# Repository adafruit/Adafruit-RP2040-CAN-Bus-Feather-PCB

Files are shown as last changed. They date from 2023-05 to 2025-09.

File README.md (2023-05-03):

## Adafruit RP2040 CAN Bus Feather with MCP2515 CAN Controller - STEMMA QT PCB

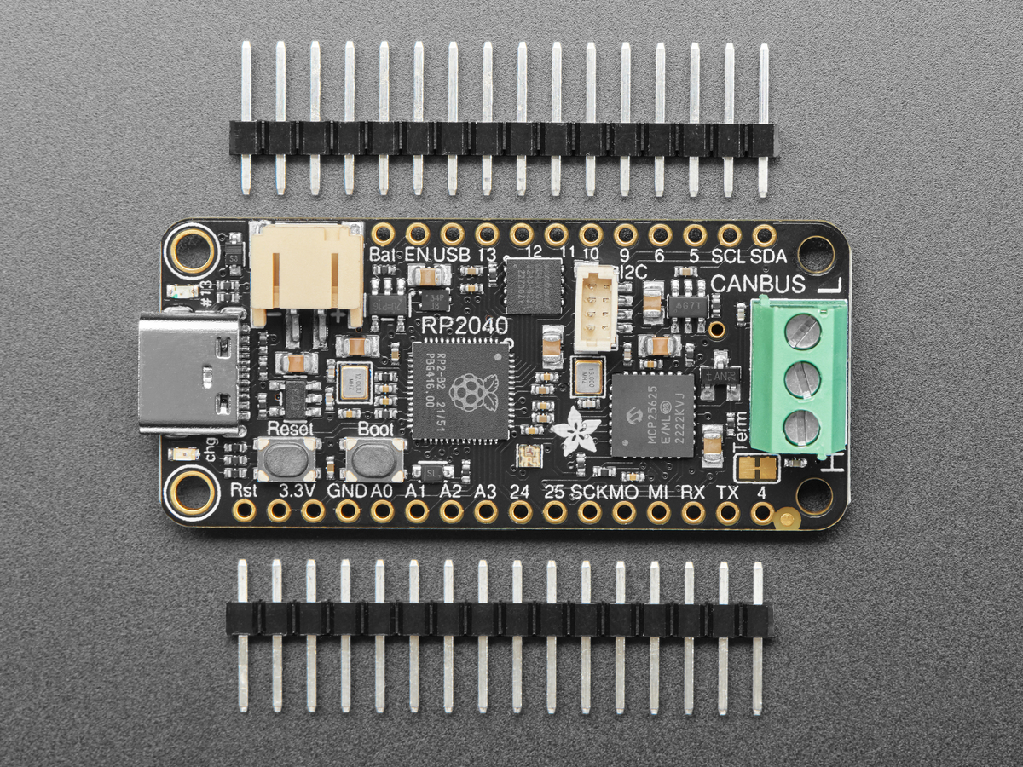
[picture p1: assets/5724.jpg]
<a href="http://www.adafruit.com/products/5724"><br/>
Click here to purchase one from the Adafruit shop</a>

PCB files for the Adafruit RP2040 CAN Bus Feather with MCP2515 CAN Controller - STEMMA QT. 

Format is EagleCAD schematic and board layout
* https://www.adafruit.com/product/5724

### Description

If you'd like to quickly get started with CAN bus interfacing, with no soldering required, our Adafruit RP2040 CAN Bus Feather comes ready-to-rock with a microcontroller, CAN chipset and terminal blocks for instant gratification. The controller used is the MCP26525 (aka a MCP2515 with built-in transciever), an extremely popular and well-supported chipset that has drivers in Arduino and CircuitPython and only requires an SPI port and two pins for chip-select and IRQ. Use it to send and receive messages in either standard or extended format at up to 1 Mbps.

Feather is the development board specification from Adafruit, and like its namesake, it is thin, light, and lets you fly! We designed Feather to be a new standard for portable microcontroller cores. We have other boards in the Feather family, check'em out here.

CAN Bus is a small-scale networking standard, originally designed for cars and, yes, busses, but is now used for many robotics or sensor networks that need better range and addressing than I2C and don't have the pins or computational ability to talk on Ethernet. CAN is 2 wire differential, which means it's good for long distances and noisy environments.

Messages are sent at about 1Mbps rate - you set the frequency for the bus and then all 'joiners' must match it, and have an address before the packet so that each node can listen in to messages just for it. New nodes can be attached easily because they just need to connect to the two data lines anywhere in the shared net. Each CAN device sends messages whenever it wants, and thanks to some clever data encoding, can detect if there's a message collision and retransmit later. 

We've added a few nice extras to this Feather to make it useful in many common CAN scenarios:

* 5V charge-pump voltage generator, so even though you are running 3.3V on a Feather board, it will generate a nice clean 5V as required by the interal transceiver.
* 3.5mm soldered terminal block quick access to the High and Low data lines as well as a ground pin, without any soldering.
* 120-ohm termination resistor on board, you can remove the termination easily by cutting the jumper marked TERM on the top of the board.
* CAN control CS, Reset, Int, standby pins connected internally so you can use any FeatherWing without pin conflicts.

At the Feather's heart is an RP2040 chip, clocked at 133 MHz and at 3.3V logic, the same one used in the Raspberry Pi Pico. This chip has a whopping 8 MB of onboard QSPI FLASH and 264K of RAM!  There's even room left over for a STEMMA QT connector for plug-and-play of I2C devices.

To make it easy to use for portable projects, we added a connector for any of our 3.7V Lithium polymer batteries and built-in battery charging. You don't need a battery, it will run just fine straight from the USB Type C connector. But, if you do have a battery, you can take it on the go, then plug in the USB to recharge. The Feather will automatically switch over to USB power when it's available.

Here're some handy specs! You get:

* Measures 2.0" x 0.9" x 0.28" (50.8mm x 22.8mm x 7mm) without headers soldered in
* Light as a (large?) feather - 6.3 grams
* RP2040 32-bit Cortex M0+ dual core running at ~133 MHz @ 3.3V logic and power
* 264 KB RAM
* 8 MB SPI FLASH chip for storing files, images and CircuitPython/MicroPython code storage. No EEPROM
* Tons of GPIO! 21 x GPIO pins with following capabilities:
	* Four 12-bit ADCs (one more than Pico)
	* Two I2C, Two SPI, and two UART peripherals, we label one for the 'main' interface in standard Feather locations
	* 16 x PWM outputs - for servos, LEDs, etc
* Built-in 200mA+ lipoly charger with charging status indicator LED
* Pin #13 red LED for general purpose blinking
* RGB NeoPixel for full-color indication.
* On-board STEMMA QT connector that lets you quickly connect any Qwiic, STEMMA QT or Grove I2C devices with no soldering!
* Both Reset button and Bootloader select button for quick restarts (no unplugging-replugging to relaunch code)
* USB Type C connector lets you access built-in ROM USB bootloader and serial port debugging
* 3.3V regulator with 500mA peak current output and power enable pin
* 4 mounting holes
* 12 MHz crystal for perfect timing.
* Support circuitry for CAN Bus using SPI interface

Comes assembled and tested, with some header. You'll need a soldering iron to attach the header for installing onto your Feather. Stacking headers will let you put another FeatherWing on top.

### License

Adafruit invests time and resources providing this open source design, please support Adafruit and open-source hardware by purchasing products from [Adafruit](https://www.adafruit.com)!

Designed by Limor Fried/Ladyada for Adafruit Industries.

Creative Commons Attribution/Share-Alike, all text above must be included in any redistribution. 
See license.txt for additional details.

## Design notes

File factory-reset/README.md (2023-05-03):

## Factory Reset file - RP2040 CAN Bus Feather with MCP2515 CAN Controller - STEMMA QT

This is the factory reset file for the RP2040 CAN Bus Feather with MCP2515 CAN Controller - STEMMA QT.

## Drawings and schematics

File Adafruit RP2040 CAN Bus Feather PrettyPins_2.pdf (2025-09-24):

# Adafruit RP2040 CAN Bus Feather

# https://www.adafruit.com/product/5724

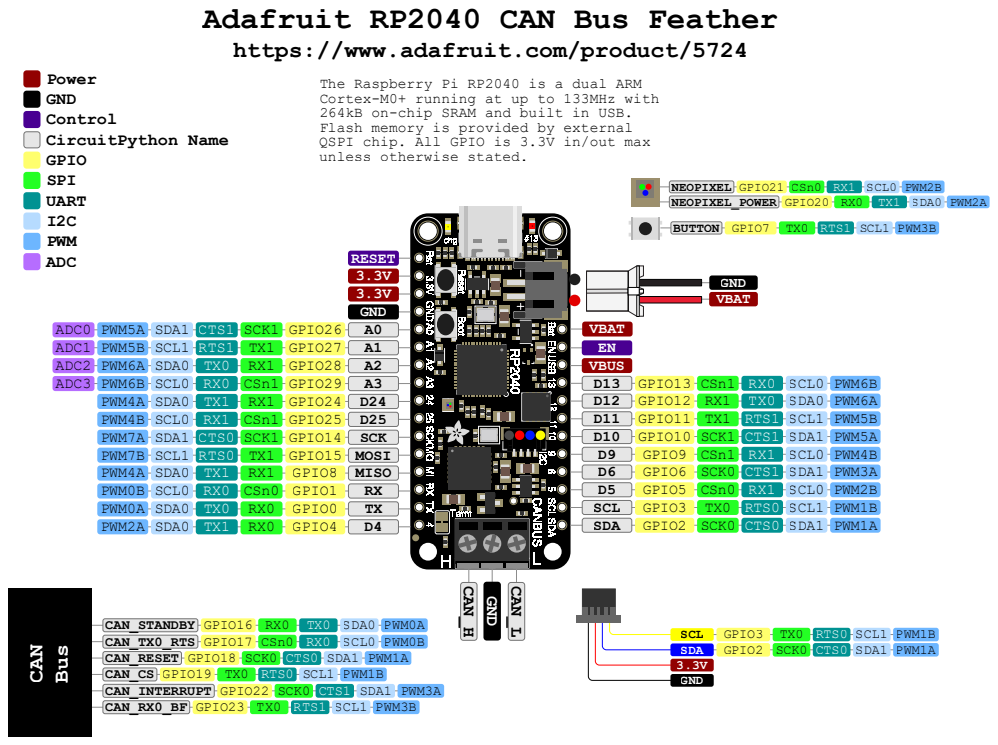
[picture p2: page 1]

The Raspberry Pi RP2040 is a dual ARM
Cortex-M0+ running at up to 133MHz with
264kB on-chip SRAM and built in USB.
Flash memory is provided by external
QSPI chip. All GPIO is 3.3V in/out max
unless otherwise stated.

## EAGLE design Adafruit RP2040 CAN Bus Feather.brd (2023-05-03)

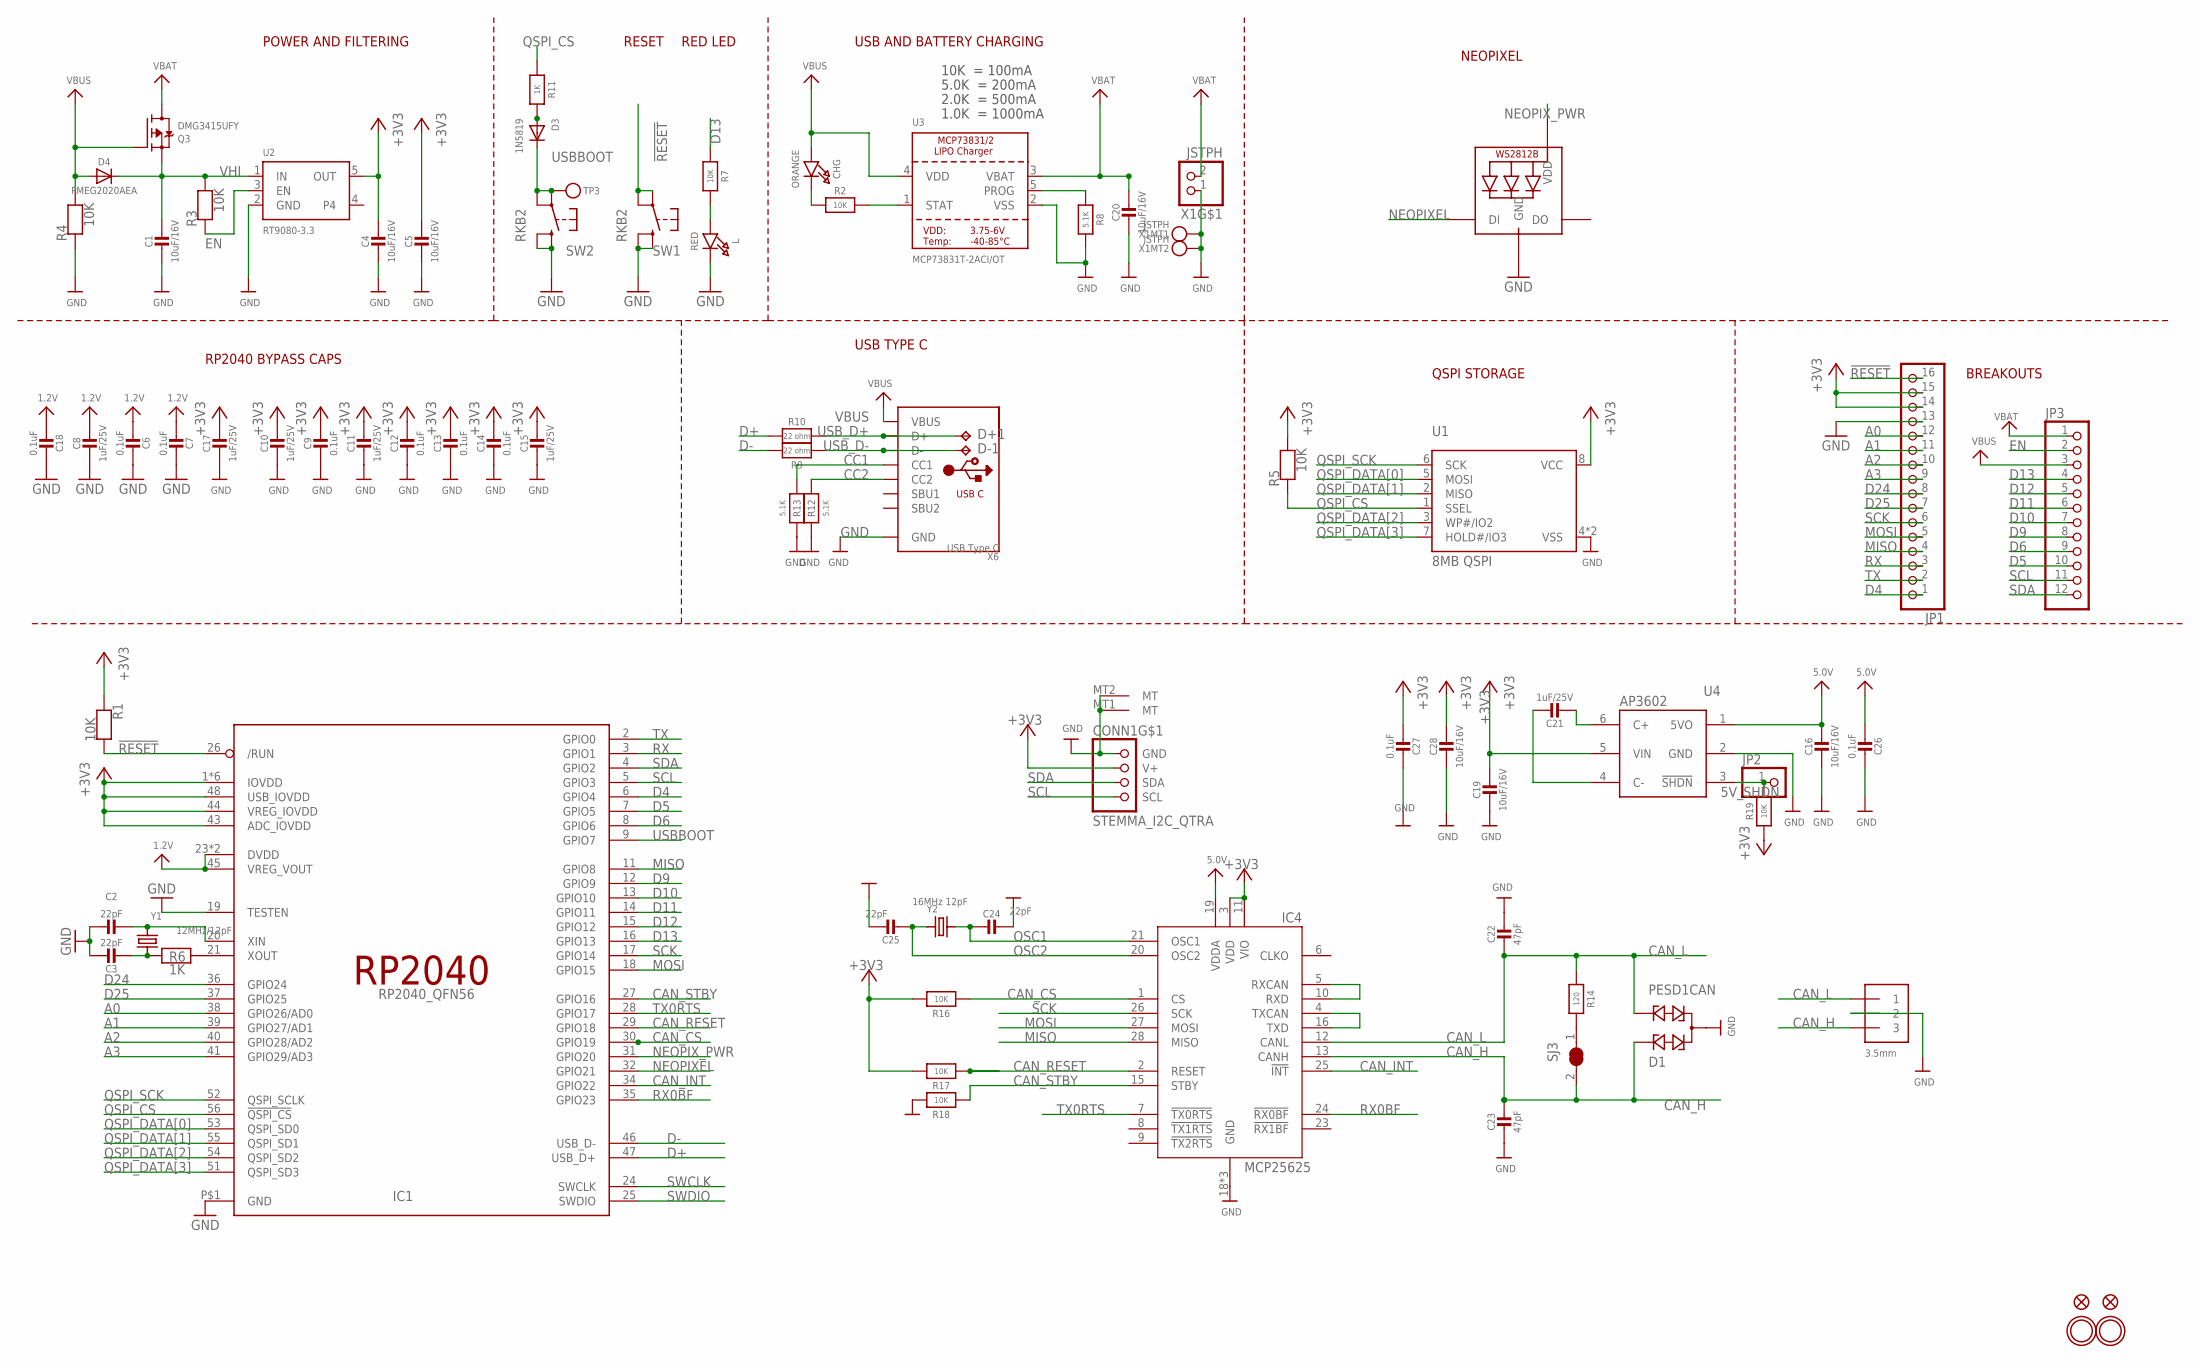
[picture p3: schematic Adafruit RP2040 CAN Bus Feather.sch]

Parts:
C1, C4, C5, C16, C19, C20, C28: 10uF/16V; 0805-NO
C2, C3, C24, C25: 22pF; _0402NO
C6, C7, C9, C12, C13, C14, C18, C26, C27: 0.1uF; _0402NO
C8, C10, C11, C15, C17, C21: 1uF/25V; _0402NO
C22, C23: 47pF; _0402NO
CHG: ORANGE; CHIPLED_0603_NOOUTLINE
CONN1: STEMMA_I2C_QTRA; JST_SH4_RA
D1: PESD1CAN; SOT23
D3: 1N5819; SOD-323_MINI
D4: PMEG2020AEA; SOD-323F
D+1: TPB1,27; B1,27
D-1: TPB1,27; B1,27
IC1: RP2040_QFN56; QFN56_7MM_REDUCEDEPAD
IC4: MCP25625; QFN28-ML_6X6MM
JP1: HEADER-1X16ROUND; 1X16_ROUND
JP2: HEADER-1X12MM; 1X01_2MM
JP3: HEADER-1X12; 1X12_ROUND
L: RED; CHIPLED_0603_NOOUTLINE
LED1: WS2812B_SK6805_1515; SK6805_1515
NEOPIX1: 3.5mm; TERMBLOCK_1X3-3.5MM
Q3: DMG3415UFY; DFN2015-3
R1, R2, R3, R4, R5, R7, R16, R17, R18, R19: 10K; _0402NO
R6, R11: 1K; _0402NO
R8, R12, R13: 5.1K; _0402NO
R9, R10: 22 ohm; _0402NO
R14: 120; _0402NO
SJ3: SOLDERJUMPER_CLOSED; SOLDERJUMPER_CLOSEDWIRE
SW1, SW2: RKB2; BTN_RKB2_4.6X2.8
TP3: TESTPOINTROUND1.5MMNO; TESTPOINT_ROUND_1.5MM_NO
U1: 8MB QSPI; USON8_4X4
U2: RT9080-3.3; SOT23-5; JLC_ROTATION 0
U3: MCP73831T-2ACI/OT; SOT23-5
U4: AP3602; SOT23-6
U$31, U$32: MOUNTINGHOLE2.5; MOUNTINGHOLE_2.5_PLATED
U$34, U$35: FIDUCIAL_1MM
X1: JSTPH; JSTPH2_BATT
X6: USB Type C; USB_C_CUSB31-CFM2AX-01-X
Y1: 12MHz/12pF; CRYSTAL_2.5X2
Y2: 16MHz 12pF; CRYSTAL_2.5X2

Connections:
1.2V: C6.2, C7.2, C8.1, C18.2, IC1.23 (DVDD), IC1.45 (VREG_VOUT), IC1.50 (DVDD)
5.0V: C16.1, C26.2, IC4.19 (VDDA), U4.1 (5VO)
5V_SHDN: JP2.1, R19.2, U4.3 (!SHDN)
!RESET: IC1.26 (/RUN), JP1.16, R1.2, SW1.A, SW1.A' (P1)
+3V3: C4.1, C5.1, C9.1, C10.1, C11.1, C12.1, C13.1, C14.1, C15.1, C17.1, C19.1, C27.2, C28.1, CONN1.2 (V+), IC1.1 (IOVDD), IC1.10 (IOVDD), IC1.22 (IOVDD), IC1.33 (IOVDD), IC1.42 (IOVDD), IC1.43 (ADC_IOVDD), IC1.44 (VREG_IOVDD), IC1.48 (USB_IOVDD), IC1.49 (IOVDD), IC4.3 (VDD), IC4.11 (VIO), JP1.14, JP1.15, R1.1, R5.2, R16.2, R17.2, R19.1, U1.8 (VCC), U2.5 (OUT), U4.5 (VIN)
A0: IC1.38 (GPIO26/AD0), JP1.12
A1: IC1.39 (GPIO27/AD1), JP1.11
A2: IC1.40 (GPIO28/AD2), JP1.10
A3: IC1.41 (GPIO29/AD3), JP1.9
CAN_CS: IC1.30 (GPIO19), IC4.1 (CS), R16.1
CAN_H: C23.1, D1.1, IC4.13 (CANH), NEOPIX1.3, SJ3.2
CAN_INT: IC1.34 (GPIO22), IC4.25 (!INT)
CAN_L: C22.2, D1.2, IC4.12 (CANL), NEOPIX1.1, R14.1
CAN_RESET: IC1.29 (GPIO18), IC4.2 (RESET), R17.1
CAN_STBY: IC1.27 (GPIO16), IC4.15 (STBY), R18.1
CC1: R13.2, X6.A5 (CC1)
CC2: R12.2, X6.B5 (CC2)
D4: IC1.6 (GPIO4), JP1.1
D5: IC1.7 (GPIO5), JP3.10
D6: IC1.8 (GPIO6), JP3.9
D9: IC1.12 (GPIO9), JP3.8
D10: IC1.13 (GPIO10), JP3.7
D11: IC1.14 (GPIO11), JP3.6
D12: IC1.15 (GPIO12), JP3.5
D13: IC1.16 (GPIO13), JP3.4, R7.1
D24: IC1.36 (GPIO24), JP1.8
D25: IC1.37 (GPIO25), JP1.7
D+: IC1.47 (USB_D+), R10.2
D-: IC1.46 (USB_D-), R9.2
EN: JP3.2, R3.1, U2.3 (EN)
GND: C1.2, C2.1, C3.1, C4.2, C5.2, C6.1, C7.1, C8.2, C9.2, C10.2, C11.2, C12.2, C13.2, C14.2, C15.2, C16.2, C17.2, C18.1, C19.2, C20.2, C22.1, C23.2, C24.1, C25.1, C26.1, C27.1, C28.2, CONN1.1 (GND), CONN1.MT1 (MT), CONN1.MT2 (MT), D1.3, IC1.19 (TESTEN), IC1.P$1 (GND), IC4.18 (GND), IC4.22 (GND), IC4.EXP (GND), JP1.13, L.C, LED1.4 (GND), NEOPIX1.2, R4.1, R8.2, R12.1, R13.1, R18.2, SW1.B (S), SW1.B' (S1), SW2.B (S), SW2.B' (S1), U1.4 (VSS), U1.PAD (VSS), U2.2 (GND), U3.2 (VSS), U4.2 (GND), X1.1, X1.NC1, X1.NC2, X6.A1B12 (GND), X6.B1A12 (GND)
MISO: IC1.11 (GPIO8), IC4.28 (MISO), JP1.4
MOSI: IC1.18 (GPIO15), IC4.27 (MOSI), JP1.5
unnamed: CHG.C, R2.1
unnamed: L.A, R7.2
unnamed: R2.2, U3.1 (STAT)
unnamed: R8.1, U3.5 (PROG)
unnamed: C2.2, IC1.20 (XIN), Y1.3 (2)
unnamed: C3.2, R6.1, Y1.1
unnamed: IC1.21 (XOUT), R6.2
unnamed: C21.1, U4.4 (C-)
unnamed: C21.2, U4.6 (C+)
unnamed: R14.2, SJ3.1
unnamed: IC4.5 (RXCAN), IC4.10 (RXD)
unnamed: IC4.4 (TXCAN), IC4.16 (TXD)
unnamed: D3.A, R11.2
NEOPIXEL: IC1.32 (GPIO21), LED1.1 (DI)
NEOPIX_PWR: IC1.31 (GPIO20), LED1.2 (VDD)
OSC1: C24.2, IC4.21 (OSC1), Y2.3 (2)
OSC2: C25.2, IC4.20 (OSC2), Y2.1
QSPI_CS: IC1.56 (!QSPI_CS), R5.1, R11.1, U1.1 (SSEL)
QSPI_DATA[0]: IC1.53 (QSPI_SD0), U1.5 (MOSI)
QSPI_DATA[1]: IC1.55 (QSPI_SD1), U1.2 (MISO)
QSPI_DATA[2]: IC1.54 (QSPI_SD2), U1.3 (WP#/IO2)
QSPI_DATA[3]: IC1.51 (QSPI_SD3), U1.7 (HOLD#/IO3)
QSPI_SCK: IC1.52 (QSPI_SCLK), U1.6 (SCK)
RX: IC1.3 (GPIO1), JP1.3
RX0BF: IC1.35 (GPIO23), IC4.24 (!RX0BF)
SCK: IC1.17 (GPIO14), IC4.26 (SCK), JP1.6
SCL: CONN1.4 (SCL), IC1.5 (GPIO3), JP3.11
SDA: CONN1.3 (SDA), IC1.4 (GPIO2), JP3.12
SWCLK: IC1.24 (SWCLK)
SWDIO: IC1.25 (SWDIO)
TX: IC1.2 (GPIO0), JP1.2
TX0RTS: IC1.28 (GPIO17), IC4.7 (!TX0RTS)
USBBOOT: D3.C, IC1.9 (GPIO7), SW2.A, SW2.A' (P1), TP3.P$1
USB_D+: D+1.TP, R10.1, X6.A6 (D+), X6.B6 (D+)
USB_D-: D-1.TP, R9.1, X6.A7 (D-), X6.B7 (D-)
VBAT: C20.1, JP3.1, Q3.3 (D), U3.3 (VBAT), X1.2
VBUS: CHG.A, D4.A, JP3.3, Q3.1 (G), R4.2, U3.4 (VDD), X6.A4B9 (VBUS), X6.B4A9 (VBUS)
VHI: C1.1, D4.C, Q3.2 (S), R3.2, U2.1 (IN)

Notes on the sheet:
POWER AND FILTERING
RESET
10K = 100mA
5.0K = 200mA
2.0K = 500mA
1.0K = 1000mA
USB AND BATTERY CHARGING
BREAKOUTS
RED LED
RP2040 BYPASS CAPS
USB TYPE C
QSPI STORAGE
NEOPIXEL

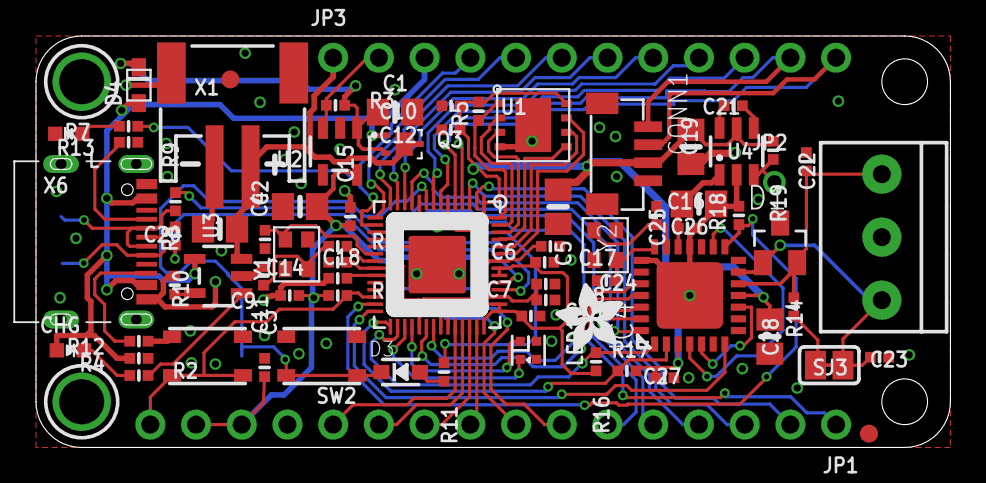
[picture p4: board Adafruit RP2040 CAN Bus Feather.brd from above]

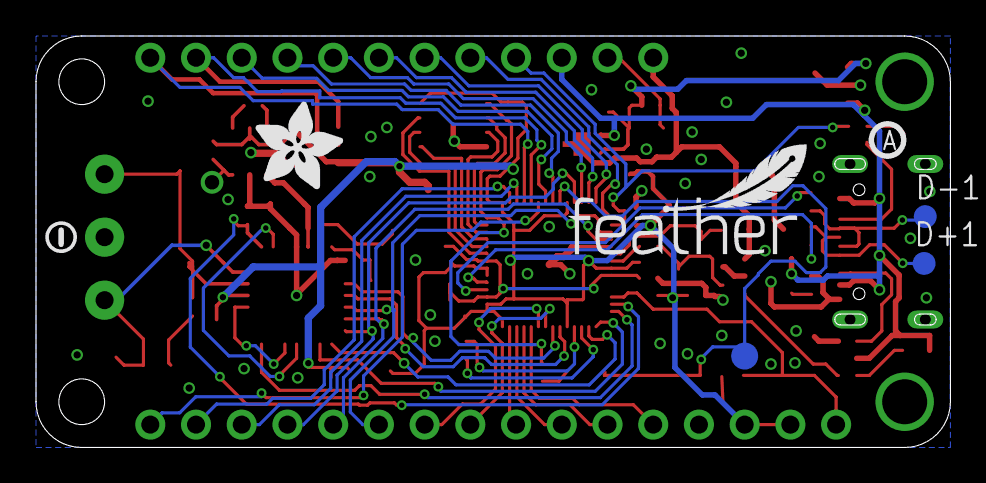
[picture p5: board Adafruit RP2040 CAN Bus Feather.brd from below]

Board: 2 copper layers, 50.8 x 22.9 mm, 153 parts (40 on the bottom side), 69 nets.

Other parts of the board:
PLABEL0: PLABEL0
PLABEL1: PLABEL1
PLABEL2: PLABEL2
PLABEL3: PLABEL3
PLABEL4: PLABEL4
PLABEL5: PLABEL5
PLABEL6: PLABEL6
PLABEL7: PLABEL7
PLABEL8: PLABEL8
PLABEL9: PLABEL9
PLABEL10: PLABEL10
PLABEL11: PLABEL11
PLABEL12: PLABEL12
PLABEL13: PLABEL13
PLABEL14: PLABEL14
PLABEL15: PLABEL15
PLABEL16: PLABEL16
PLABEL17: PLABEL17
PLABEL18: PLABEL18
PLABEL19: PLABEL19
PLABEL20: PLABEL20
PLABEL21: PLABEL21
PLABEL22: PLABEL22
PLABEL23: PLABEL23
PLABEL24: PLABEL24
PLABEL25: PLABEL25
PLABEL26: PLABEL26
PLABEL27: PLABEL27
PLABEL28: PLABEL28
PLABEL29: PLABEL29
PLABEL30: PLABEL30
PLABEL31: PLABEL31
PLABEL32: PLABEL32
PLABEL33: PLABEL33
PLABEL34: PLABEL34
PLABEL35: PLABEL35
PLABEL36: PLABEL36
PLABEL37: PLABEL37
PLABEL38: PLABEL38
PLABEL39: PLABEL39
PLABEL40: PLABEL40
PLABEL41: PLABEL41
PLABEL42: PLABEL42
PLABEL43: PLABEL43
PLABEL44: PLABEL44
PLABEL45: PLABEL45
PLABEL46: PLABEL46
PLABEL47: PLABEL47
PLABEL48: PLABEL48
PLABEL49: PLABEL49
PLABEL50: PLABEL50
PLABEL51: PLABEL51
PLABEL52: PLABEL52
PLABEL53: PLABEL53
PLABEL54: PLABEL54
PLABEL55: PLABEL55
PLABEL56: PLABEL56
PLABEL57: PLABEL57
PLABEL58: PLABEL58
PLABEL59: PLABEL59
PLABEL60: PLABEL60
PLABEL61: PLABEL61
PLABEL62: PLABEL62
PLABEL63: PLABEL63
PLABEL64: PLABEL64
PLABEL65: PLABEL65
PLABEL66: PLABEL66
PLABEL67: PLABEL67
PLABEL68: PLABEL68
PLABEL69: PLABEL69
U$13: PCBFEAT-REV-040
U$42: ADAFRUIT_3.5MM
U$53: SYMBOL_MINUS
U$54: ADAFRUIT_5MM
U$60: FEATHERLOGO_SMALL

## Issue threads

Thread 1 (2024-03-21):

Not reading CAN bus after solidering

MBS212, 2024-03-21:
Hi, all.

If anyone have more experience with this board.

I have an issue came out with this board after I soldered the pcb terminals to it (see the pics attached).

Before it was reading the bus very well and did not have any problems.

Also, can anyone explain better which pins I can connect my devices (relays, servos, ...) to the board, and to which I must not connect if I want the board's CAN bus read and write to work correctly?

I have the pin 5 connected that controls the servo, and the CAN H, CAN L.
Nothing else is connected.

When I try
if( mcp.parsePacket() )
{
  Serial.println("Inside mcp parse");
}

Serial displays nothing at all.

thank you.

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

caternuson, 2024-03-21:
For tech support, please post in the forums:
https://forums.adafruit.com/

Closed 2024-03-21.

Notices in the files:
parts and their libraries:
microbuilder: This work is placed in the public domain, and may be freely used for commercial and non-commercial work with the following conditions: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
